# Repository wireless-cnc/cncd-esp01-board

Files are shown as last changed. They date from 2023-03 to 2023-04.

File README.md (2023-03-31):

# CNCD ESP-01 Board

🔴 **WARNING** - the hardware / firmware of the project is not stable and has a showstopper issue https://github.com/wireless-cnc/cncd-esp01/issues/1

The motherboard for ESP-01 running CNCD firmware.

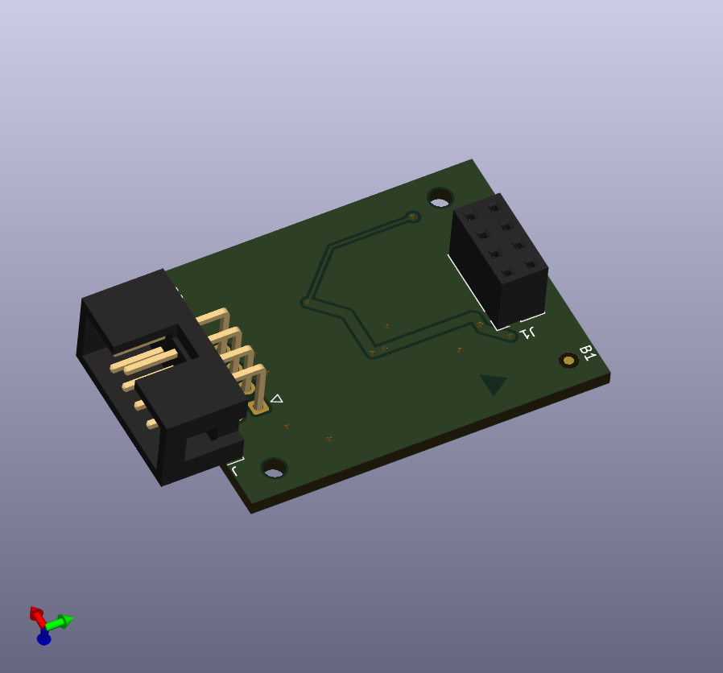
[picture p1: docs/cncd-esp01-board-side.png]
Board side view

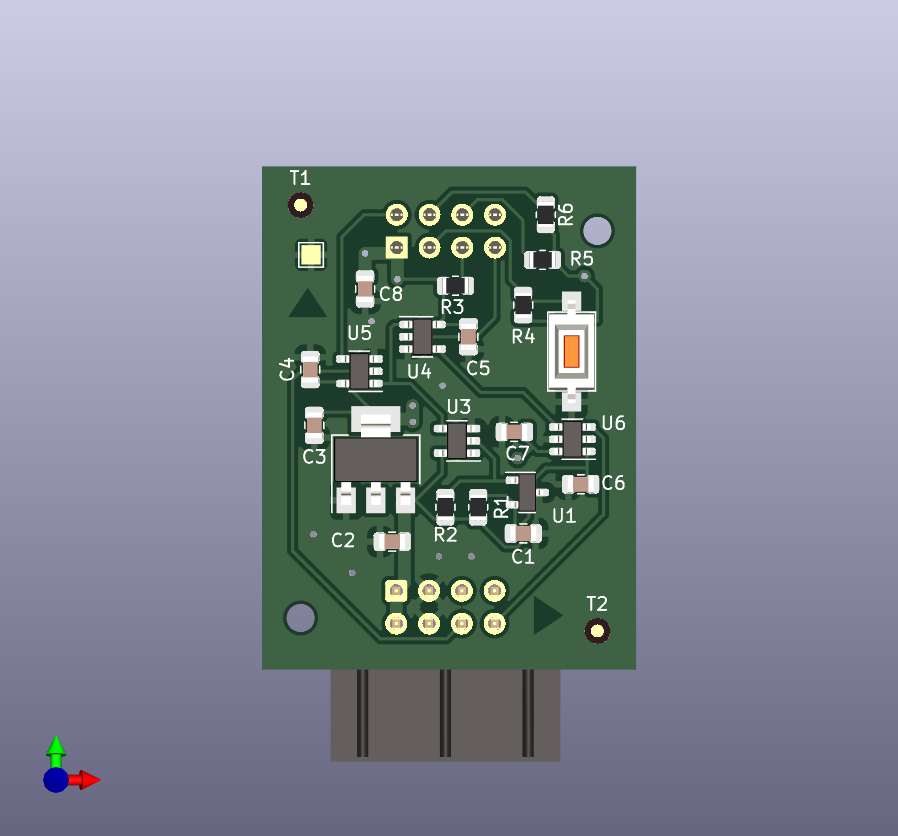
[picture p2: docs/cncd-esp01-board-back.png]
Board back view


## How to use it

1. Grab the ESP-01 board and flash it with [CNCD firmware](https://github.com/wireless-cnc/cncd-esp01)
2. Insert ESP-01 into the slot, the arrow on the top side shows the direction of the ESP-01 antenna
3. Connect the board with the CNC Controller Board using [Offline Controller's cable](https://docs.sainsmart.com/article/zinzutpbhg-genmitsu-3018-pro-offline-controller-guide)
4. Power on CNC
5. Configure WiFi connection of CNCD 
6. Install and run [Wireless CNC Controller](https://github.com/wireless-cnc/cnc-controller/releases)
7. Now you can upload CNC job to controller and launch it!

## What's there

This repo contains source files developed in KiCAD 7.0:

* Board schematic
* PCB layout
* Gerber files

## Board features

* IDP connector compatible with CNC-3018 offline controllers
* Onboard 5V to 3.3V voltage regulator for powering ESP chip
* Delayed serial interface initialization
* Voltage level conversion from CNC 5V serial to ESP's 3.3V serial

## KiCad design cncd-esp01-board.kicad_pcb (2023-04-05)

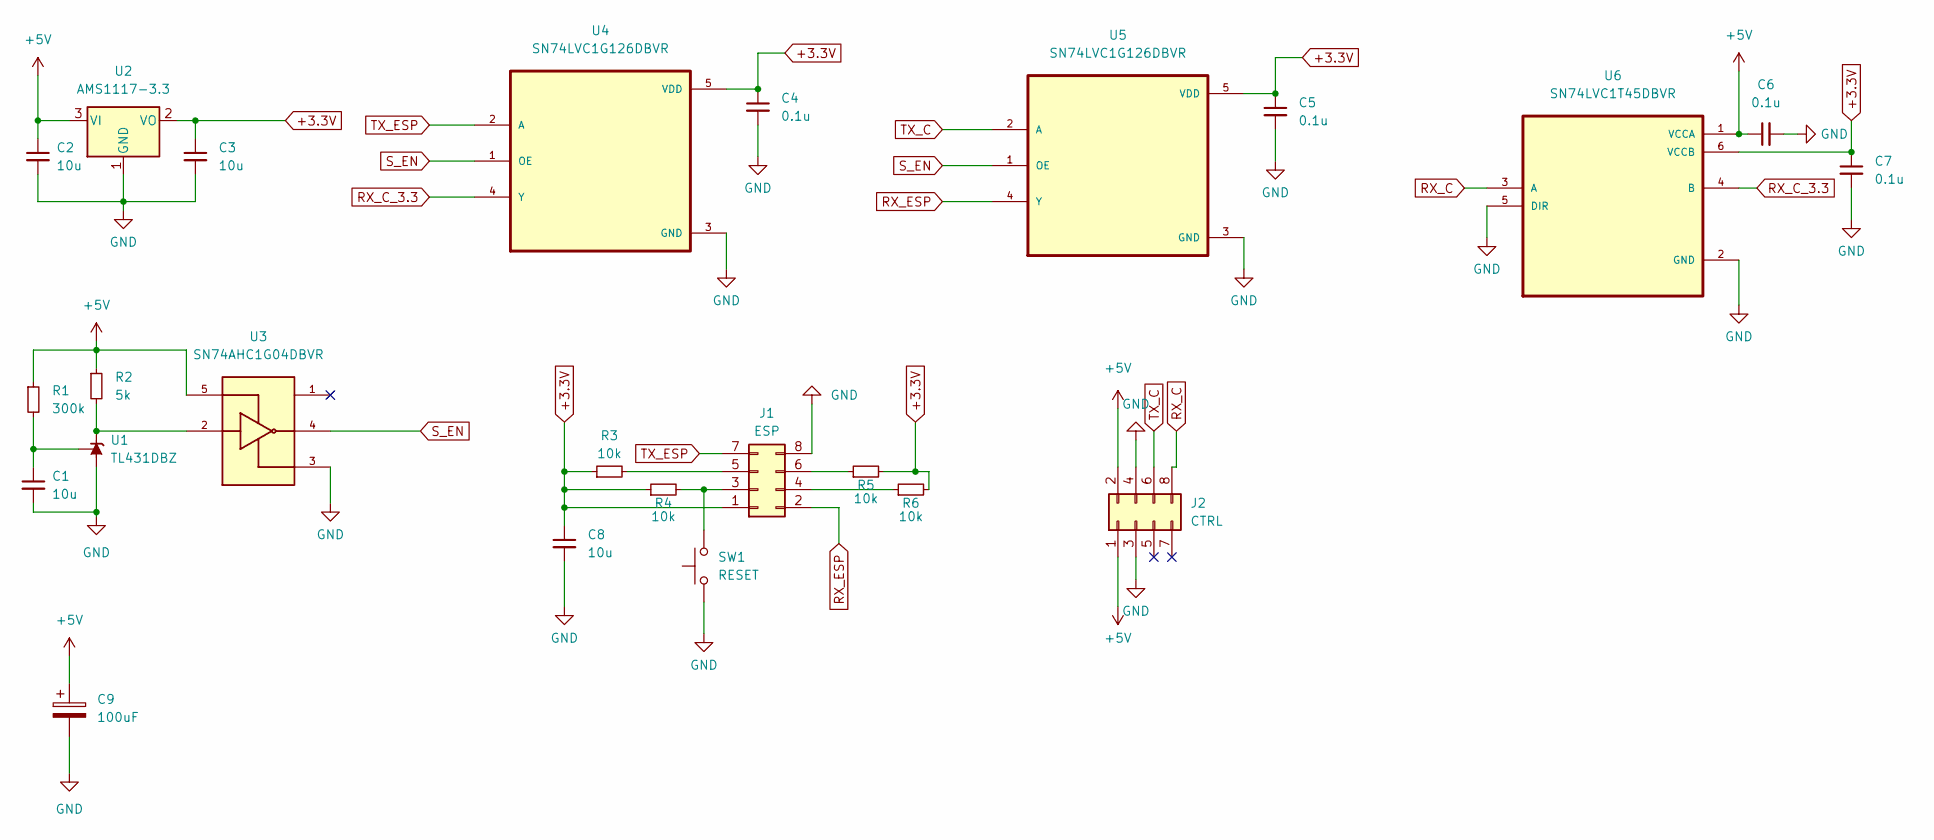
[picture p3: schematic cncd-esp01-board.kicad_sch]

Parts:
C1, C2, C3, C8: 10u; C_0805_2012Metric
C4, C5, C6, C7: 0.1u; C_0805_2012Metric
C9: 100uF; CP_EIA-3528-21_Kemet-B
J1: ESP; PinSocket_2x04_P2.54mm_Vertical
J2: CTRL; IDC-Header_2x04_P2.54mm_Horizontal
R1: 300k; R_0805_2012Metric
R2: 5k; R_0805_2012Metric
R3, R4, R5, R6: 10k; R_0805_2012Metric
SW1: RESET; SW_SPST_CK_RS282G05A3
U1: TL431DBZ; SOT-23
U2: AMS1117-3.3; SOT-223-3_TabPin2
U3: SN74AHC1G04DBVR; SOT-23-5; PARTREV AD
U4, U5: SN74LVC1G126DBVR; SOT-23-5
U6: SN74LVC1T45DBVR; SOT-23-6

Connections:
+3.3V: C3.1, C4.1, C5.1, C7.1, C8.1, J1.1, R3.1, R4.1, R5.2, R6.2, U2.2 (VO), U4.5 (VDD), U5.5 (VDD), U6.6 (VCCB)
+5V: C2.1, C6.1, C9.1, J2.1, J2.2, R1.1, R2.1, U2.3 (VI), U3.5, U6.1 (VCCA)
GND: C1.2, C2.2, C3.2, C4.2, C5.2, C6.2, C7.2, C8.2, C9.2, J1.8, J2.3, J2.4, SW1.1, U1.3 (A), U2.1 (GND), U3.3, U4.3 (GND), U5.3 (GND), U6.2 (GND), U6.5 (DIR)
unnamed: J1.3, R4.2, SW1.2
unnamed: J1.4, R6.1
unnamed: J1.5, R3.2
unnamed: J1.6, R5.1
unnamed: R2.2, U1.1 (K), U3.2
unnamed: C1.1, R1.2, U1.2 (REF)
RX_C: J2.8, U6.3 (A)
RX_C_3.3: U4.4 (Y), U6.4 (B)
RX_ESP: J1.2, U5.4 (Y)
S_EN: U3.4, U4.1 (OE), U5.1 (OE)
TX_C: J2.6, U5.2 (A)
TX_ESP: J1.7, U4.2 (A)

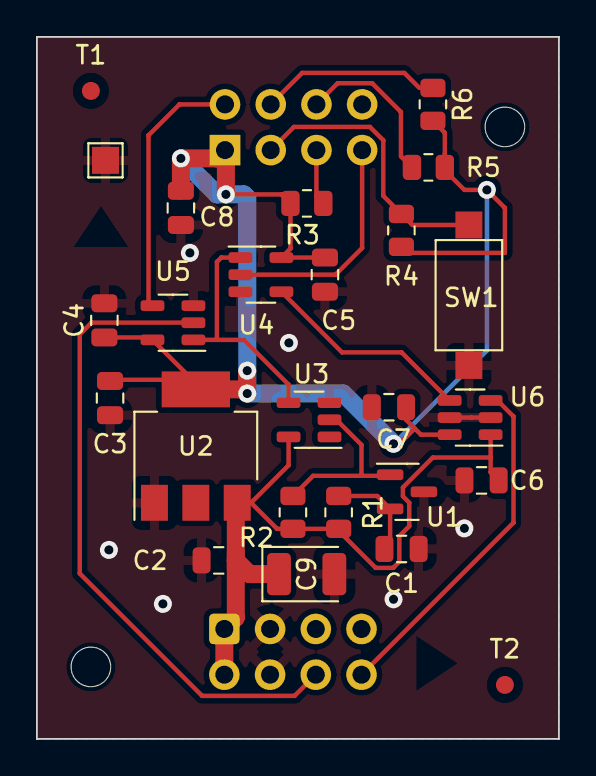
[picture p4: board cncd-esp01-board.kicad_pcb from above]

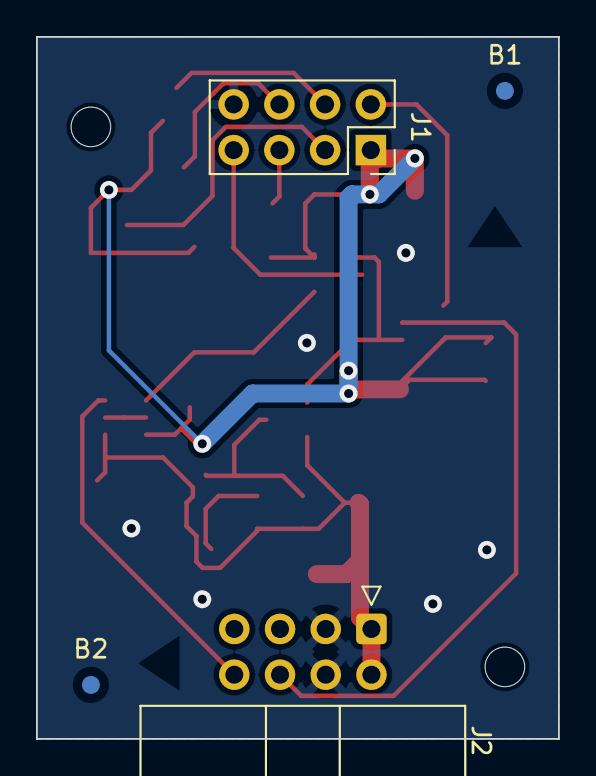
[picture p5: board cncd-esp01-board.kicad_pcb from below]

Board: 2 copper layers, 29.0 x 39.0 mm, 28 parts (4 on the bottom side), 15 nets.

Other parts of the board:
B1, B2: Fiducial_1mm_Mask2mm
T1, T2: Fiducial_1mm_Mask2mm

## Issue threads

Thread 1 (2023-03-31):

Potential hardware problems with power or voltage level shifting causing the firmware to fail

Glebka, 2023-03-31:
See https://github.com/wireless-cnc/cncd-esp01/issues/1 for more details

Need to check hardware design and fix problems if found.

Glebka, 2023-04-05:
Looks like soldering an extra 100uF onto 5V power line from CNC does solve the issue.
Will continue monitoring

Glebka, 2023-04-26:
Finally, solved the issue by using extra capacitor and by reducing baud rate to 57600.

Many thanks to Reddit Community for help with that issue: https://www.reddit.com/r/AskElectronics/comments/127ldfb/please_help_investigate_uart_problems_and/

Closed 2023-04-26.
